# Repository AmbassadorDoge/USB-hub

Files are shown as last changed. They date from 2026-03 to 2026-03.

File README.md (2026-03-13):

# USB HUB

- 2 USB-C 2.0 ports
- 2 USB-A 3.1 gen 1 ports
- Using TUSB8042, USB-A upstream
- ~80x54mm, all recepticles

- Need USB-A to ~ to connect with computer
- Only for data, please do not try to use for charging!

Made this because I needed a cheap and small USB hub I could carry so that my main hub could be kept at home. 

## Assembly
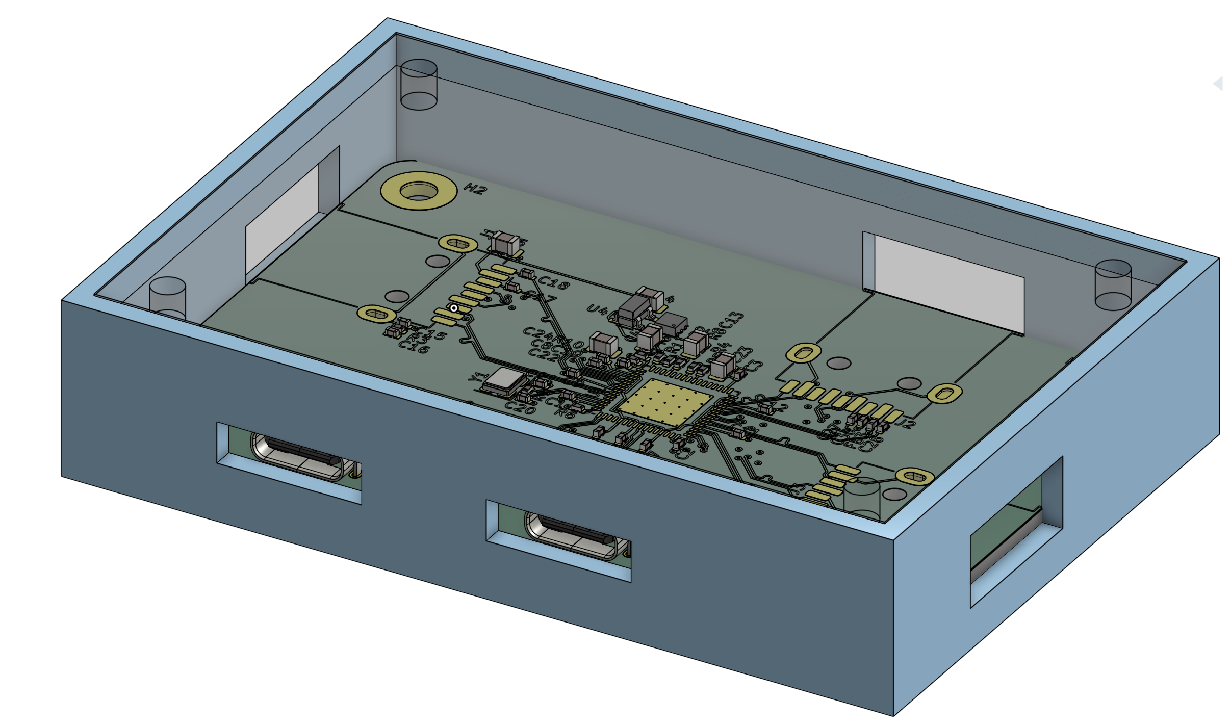
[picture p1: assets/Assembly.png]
asm


## PCB
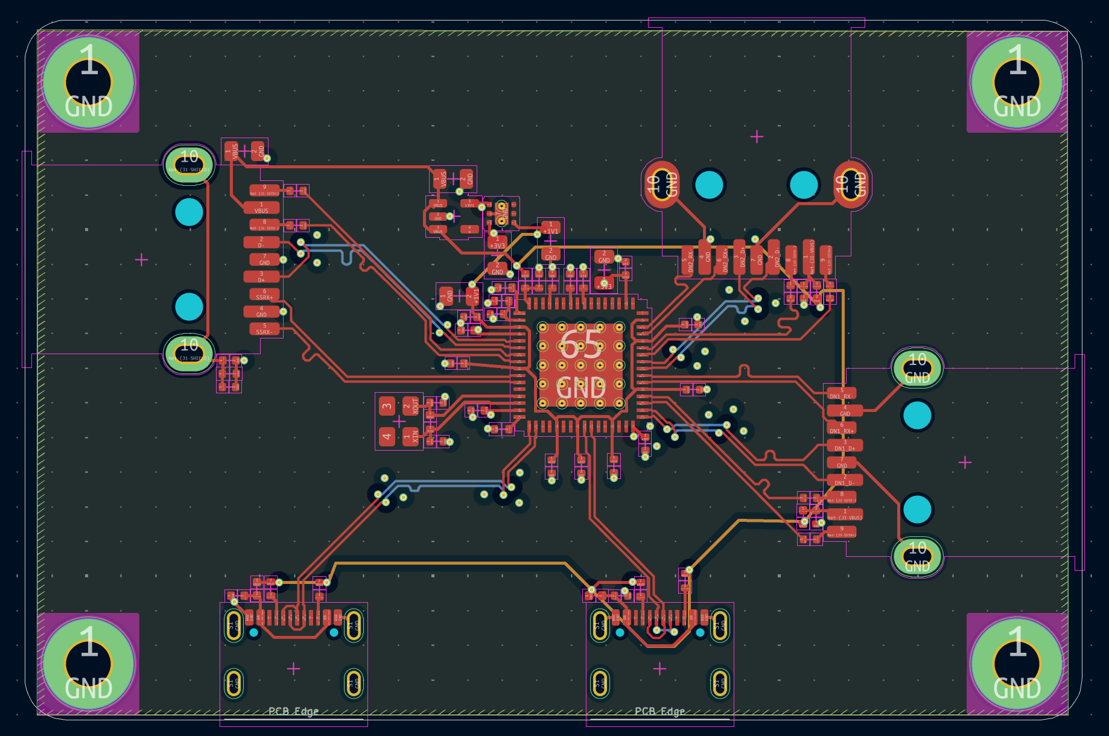
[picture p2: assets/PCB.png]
pcb


|item |price|link |
|---|-----|---|
|PCB | $7  | jlcpcb.com |
|PCBA | $45 | jlcpcb.com |
|acrylic| $5  | https://www.amazon.com/FixtureDisplays%C2%AE-Nominal-Plexiglass-Tabletop-15643-6X6-NF/dp/B099Z3Y54B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|
|total  | $52 | - |

Made using KiCad & Onshape
[Onshape link](https://cad.onshape.com/documents/166e42de1b24c1a1952d9a0a/w/ee2553dc721c4a7be2e464a8/e/28846ffd7bfde794f9e65d97)

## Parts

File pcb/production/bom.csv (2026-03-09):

Designator | Footprint | Quantity | Value | LCSC Part #
C1, C10, C11, C12, C15, C17, C18, C2, C22, C25, C26, C27, C28, C29, C3, C30, C31, C32, C6, C7, C8, C9 | 0402 | 22 | 0.1uF
C13, C14, C23, C24, C4, C5 | 0805 | 6 | 10uF
C16 | 0402 | 1 | 0.001uF
C19 | 0402 | 1 | 1uF
C20, C21 | 0402 | 2 | 18pF
FB1, FB2, FB3, FB4 | 0402 | 4 | 220@100MHz
J1, J2, J3 | USB3_A_Receptacle_Wuerth_692122030100 | 3 | USB3_A
J4, J5 | USB_C_Receptacle_GCT_USB4105-xx-A_16P_TopMnt_Horizontal | 2 | USB_C_Receptacle_USB2.0_16P
R1 | 0402 | 1 | 90.9k
R10, R2 | 0402 | 2 | 10k
R11, R12, R13, R14 | 0402 | 4 | 56k
R3, R9 | 0402 | 2 | 1M
R4, R5, R7, R8 | 0402 | 4 | 4.7k
R6 | 0402 | 1 | 9.53k
U1 | QFN-64-1EP_9x9mm_P0.5mm_EP6x6mm_ThermalVias | 1 | TUSB8041
U2 | WSON-6-1EP_2x2mm_P0.65mm_EP1x1.6mm_ThermalVias | 1 | LP5912-1.1DRV
U4 | SOT-23-5 | 1 | TLV75533PDBV
Y1 | Crystal_SMD_3225-4Pin_3.2x2.5mm | 1 | 24MHz

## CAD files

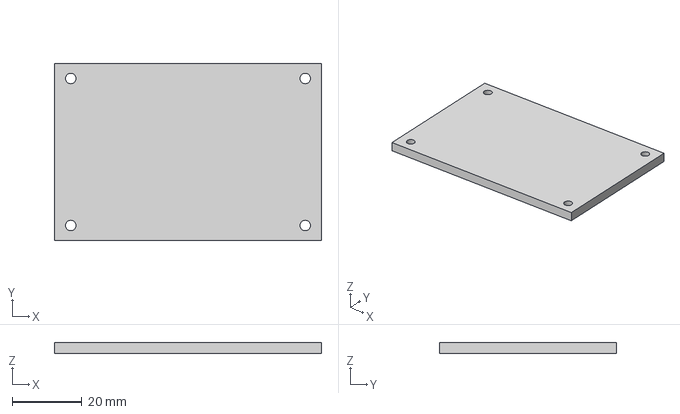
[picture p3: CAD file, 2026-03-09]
CAD/Acrylic Top.step
76.3 x 50.5 x 3.17 mm

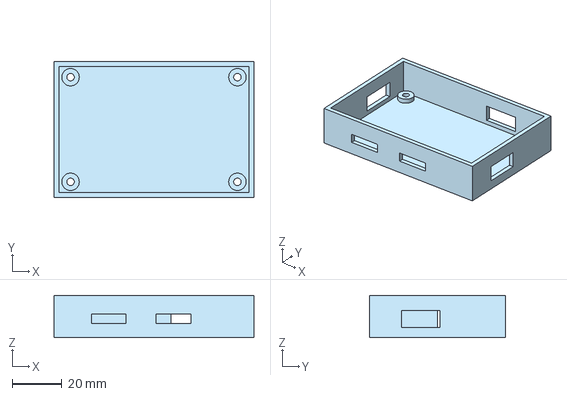
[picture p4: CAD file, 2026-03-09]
CAD/Holder.step
80.3 x 54.5 x 17.0 mm

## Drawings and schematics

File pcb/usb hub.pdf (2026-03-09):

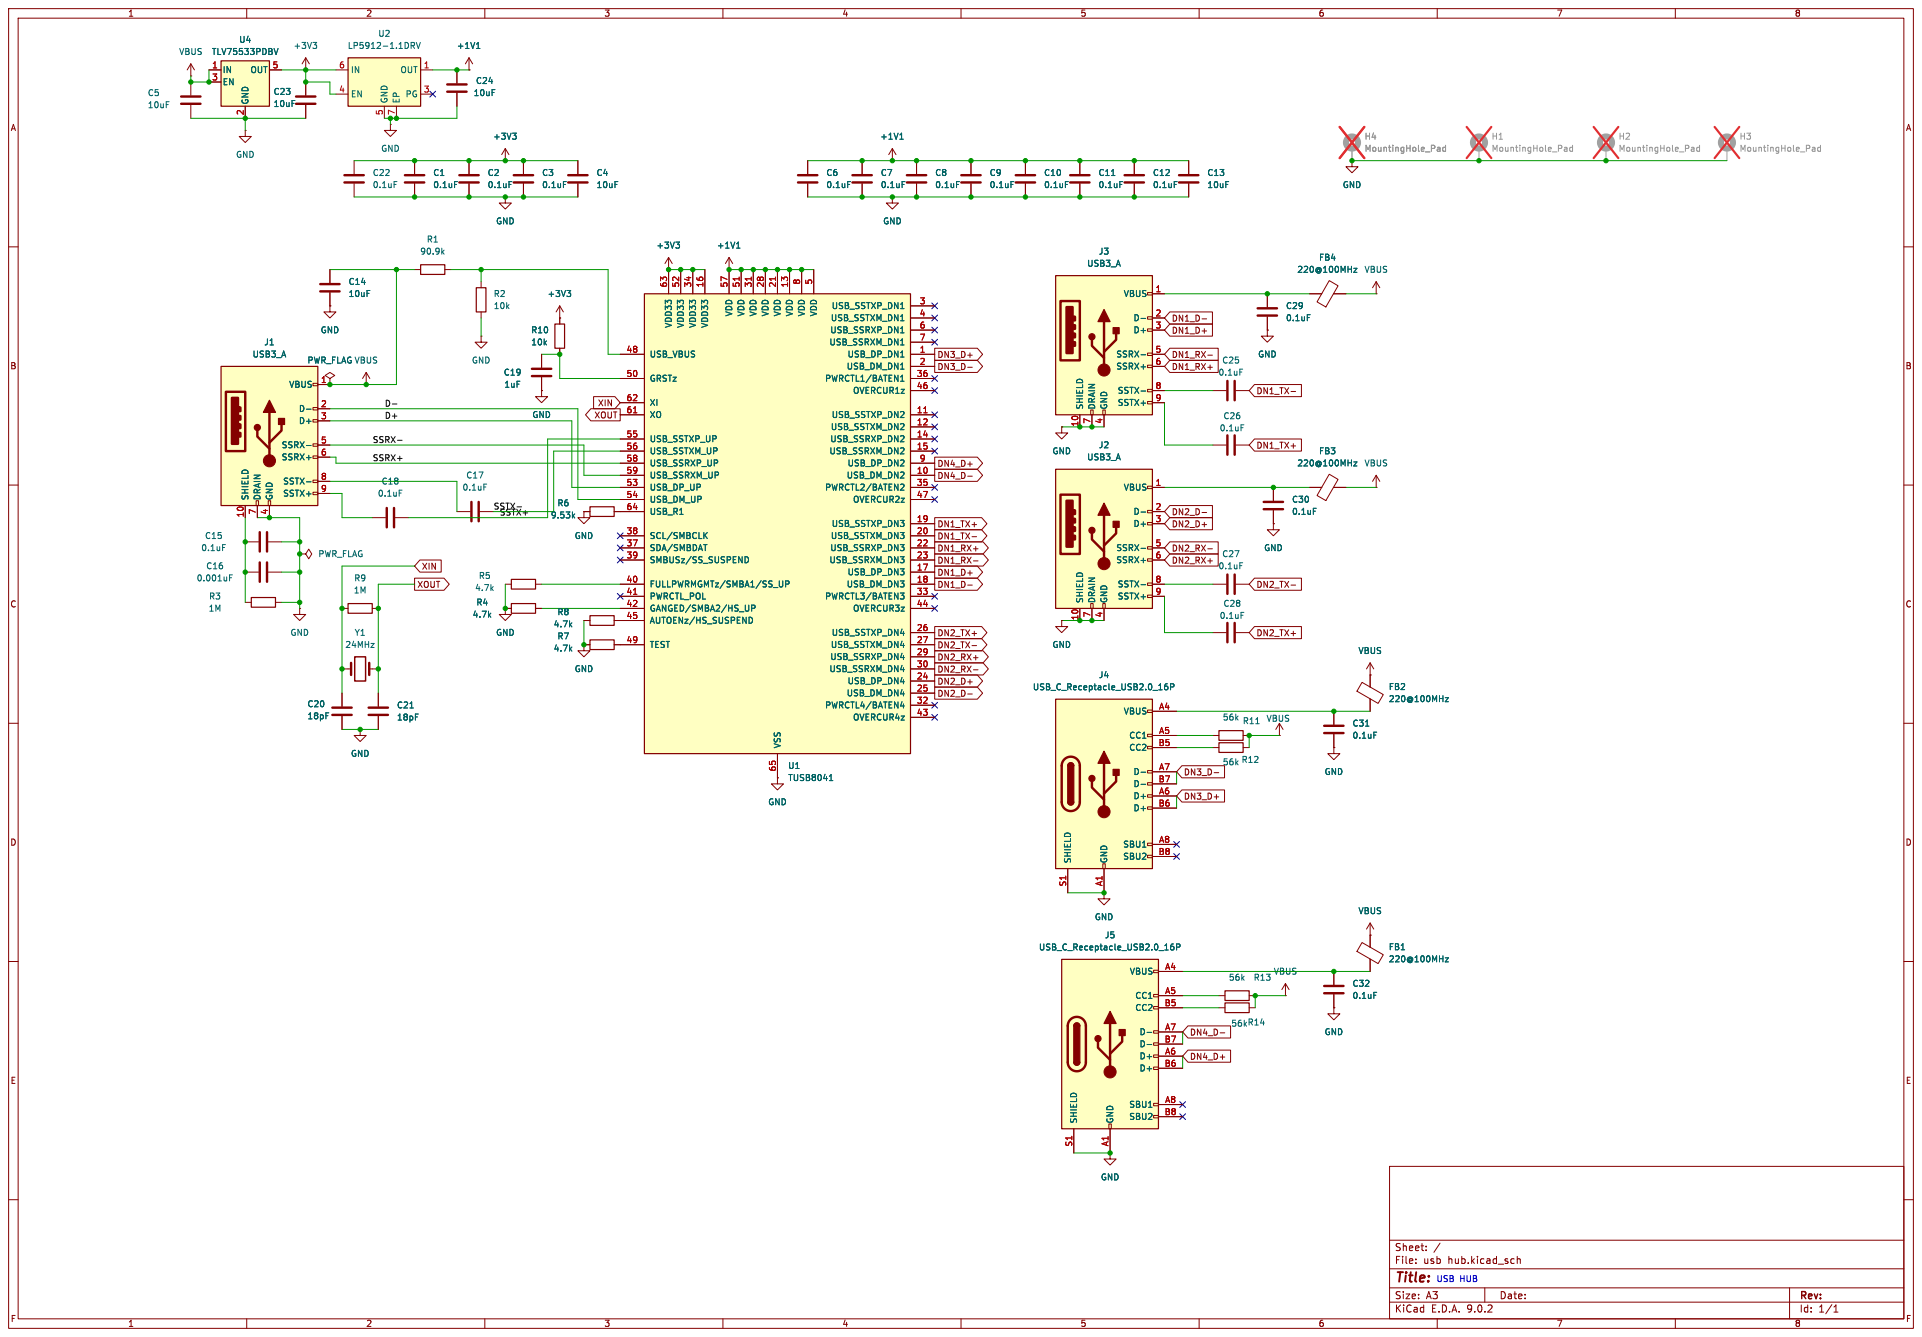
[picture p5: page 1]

2 OUT 5 U4 VBUS TLV75533PDBV USB_VBUS 48 GRSTz 50 XI 62 XO 61 USB_SSTXP_UP 55 USB_SSTXM_UP 56 USB_SSRXP_UP 58 USB_SSRXM_UP 59 USB_DP_UP 53 USB_DM_UP 54 USB_R1 64 SCL/SMBCLK 38 SDA/SMBDAT 37 SMBUSz/SS_SUSPEND 39 FULLPWRMGMTz/SMBA1/SS_UP 40 PWRCTL_POL 41 GANGED/SMBA2/HS_UP 42 AUTOENz/HS_SUSPEND 45 TEST 49 VDD33 63 VDD33 52 VDD33 34 VDD33 16 VDD 57 VDD 51 VDD 31 VDD 28 VDD 21 VSS 65 VDD 13 VDD

4 VBUS 1 D- 2 D+ 3 SSRX- 5 SSRX+ 6 SSTX- 8 SSTX+ 9 +3V3 +1V1 C6

4 VBUS 1 D- 2 D+ 3 SSRX- 5 SSRX+ 6 SSTX- 8 SSTX+ 9 C10

4 VBUS 1 D- 2 D+ 3 SSRX- 5 SSRX+ 6 SSTX- 8 SSTX+ 9

4 VBUS 1 D- 2 D+ 3 SSRX- 5 SSRX+ 6 SSTX- 8 SSTX+ 9 VBUS

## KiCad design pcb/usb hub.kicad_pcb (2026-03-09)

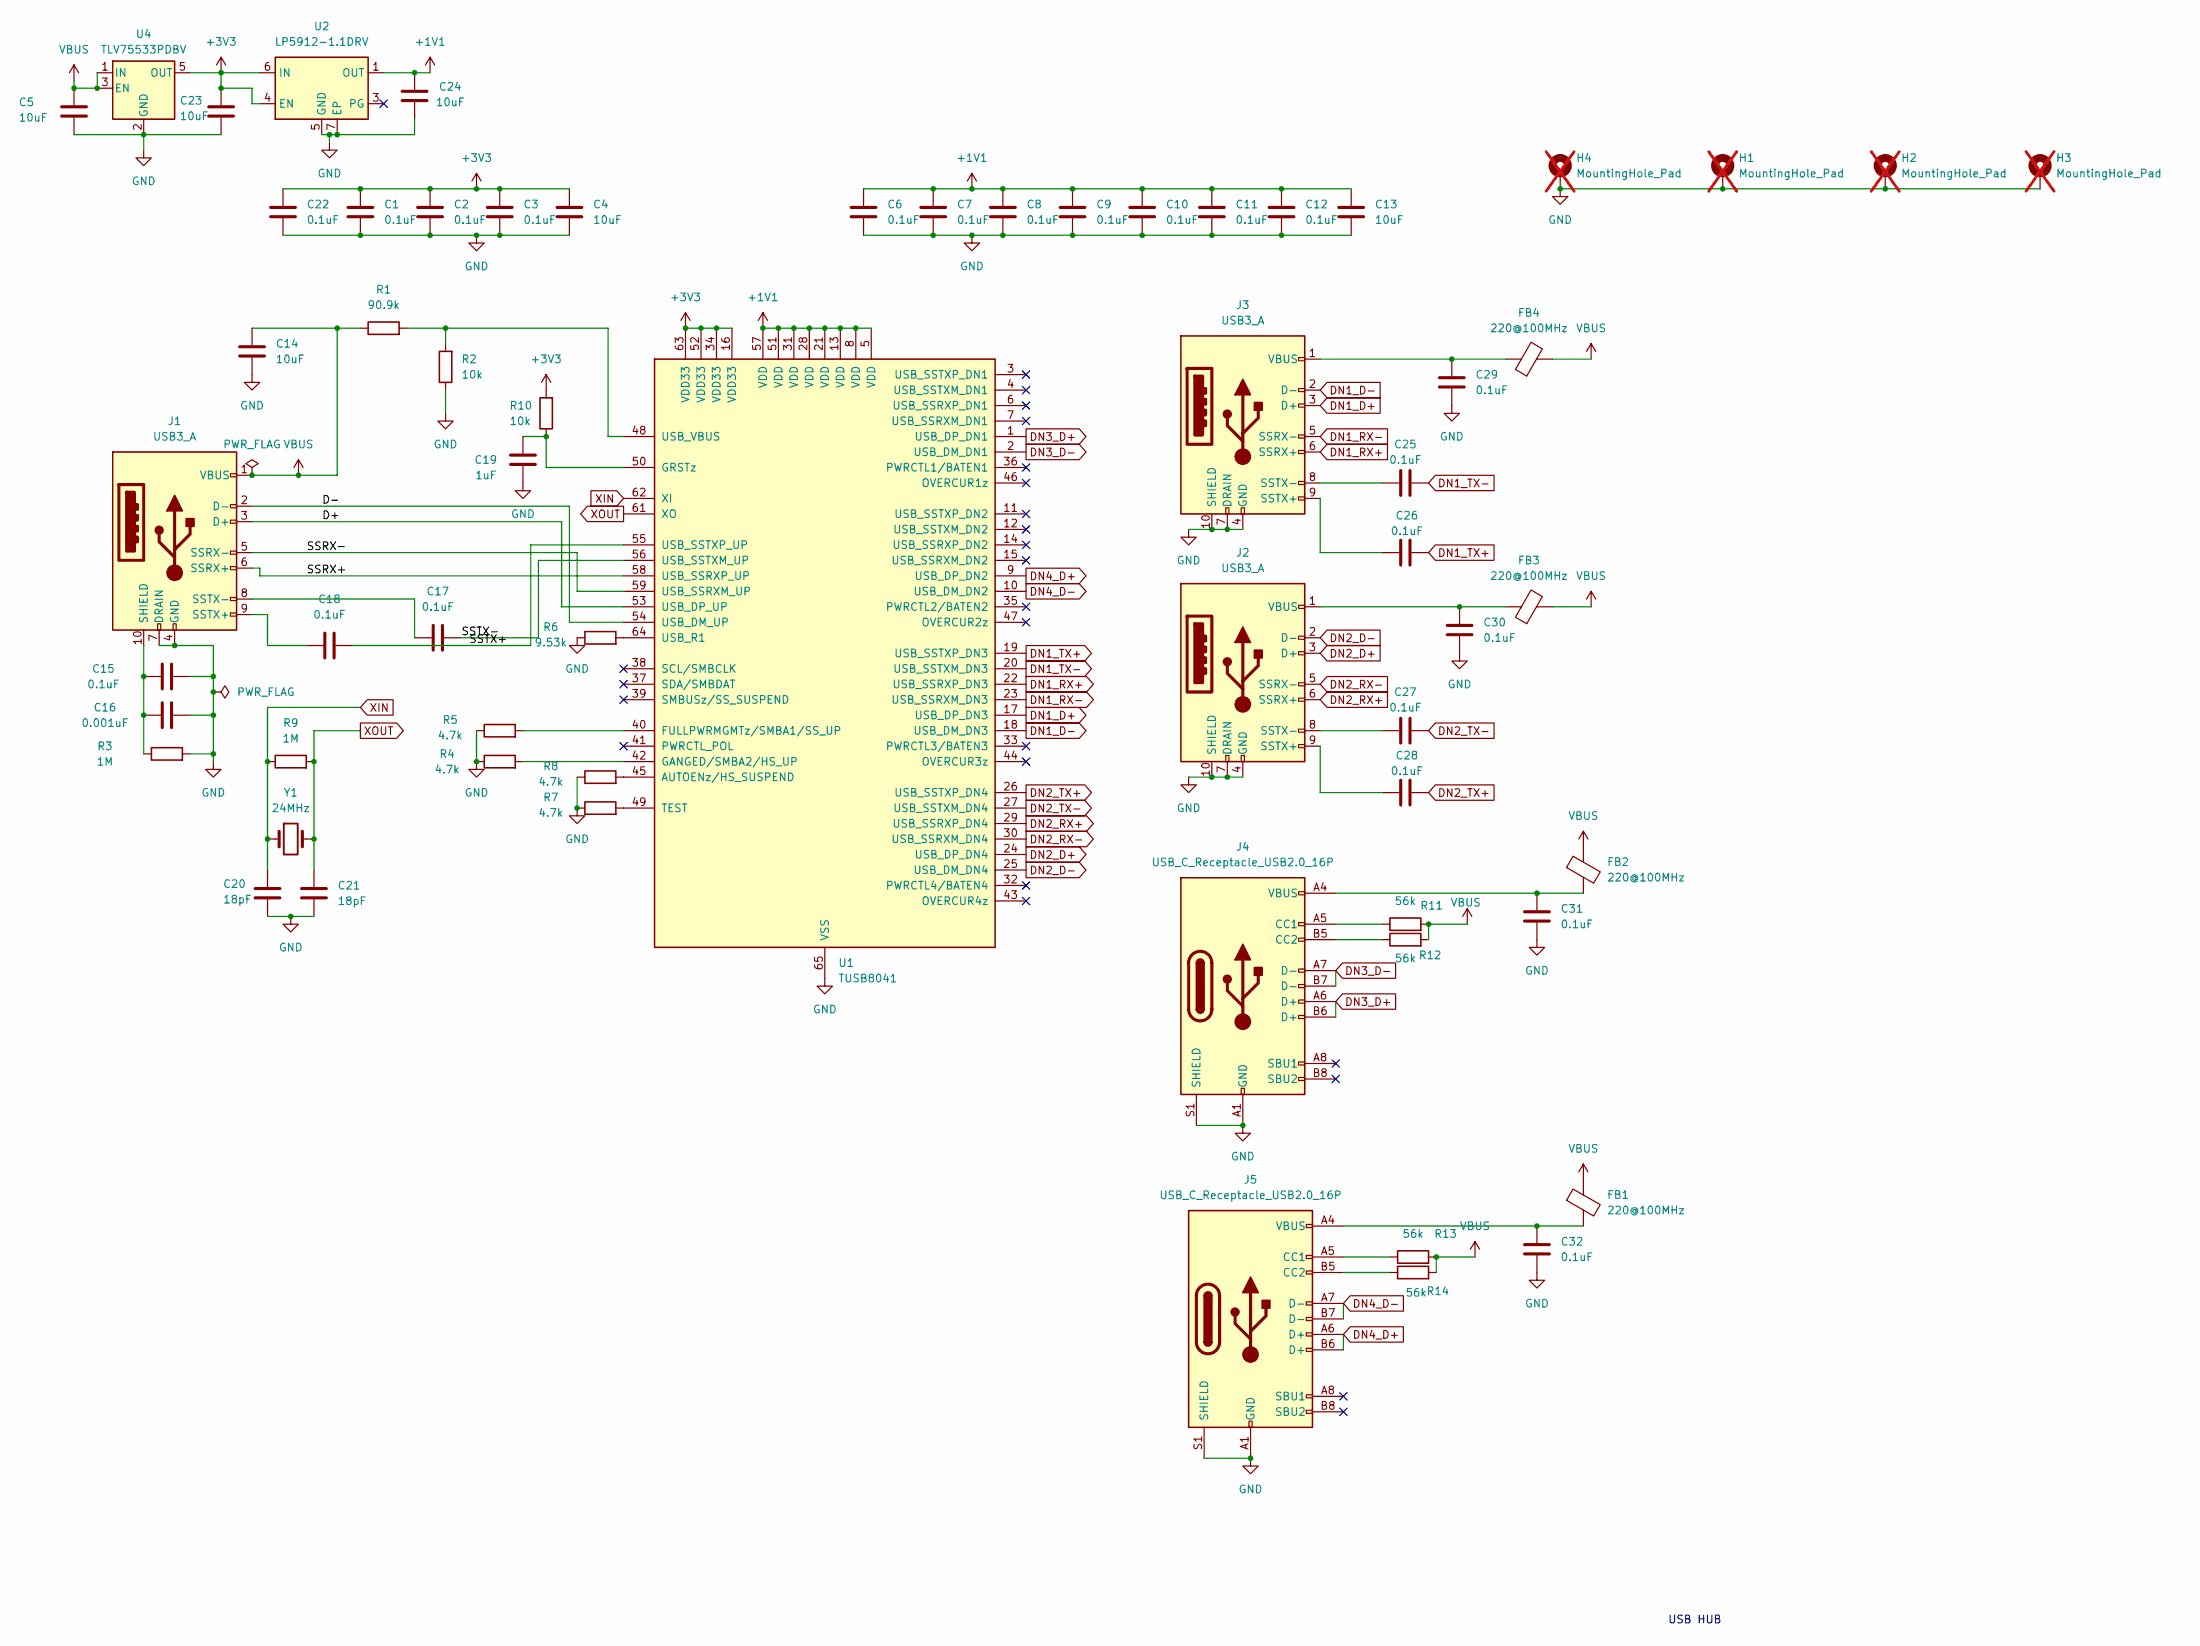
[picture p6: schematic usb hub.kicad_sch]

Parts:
C1, C2, C3, C6, C7, C8, C9, C10, C11, C12, C15, C17, C18, C22, C25, C26, C27, C28, C29, C30, C31, C32: 0.1uF; C_0402_1005Metric
C4, C5, C13, C14, C23, C24: 10uF; C_0805_2012Metric
C16: 0.001uF; C_0402_1005Metric
C19: 1uF; C_0402_1005Metric
C20, C21: 18pF; C_0402_1005Metric
FB1, FB2, FB3, FB4: 220@100MHz; L_0402_1005Metric
H1, H2, H3, H4: MountingHole_Pad; MountingHole_3.2mm_M3_Pad; not fitted
J1, J2, J3: USB3_A; USB3_A_Receptacle_Wuerth_692122030100
J4, J5: USB_C_Receptacle_USB2.0_16P; USB_C_Receptacle_GCT_USB4105-xx-A_16P_TopMnt_Horizontal
R1: 90.9k; R_0402_1005Metric
R2, R10: 10k; R_0402_1005Metric
R3, R9: 1M; R_0402_1005Metric
R4, R5, R7, R8: 4.7k; R_0402_1005Metric
R6: 9.53k; R_0402_1005Metric
R11, R12, R13, R14: 56k; R_0402_1005Metric
U1: TUSB8041; QFN-64-1EP_9x9mm_P0.5mm_EP6x6mm_ThermalVias
U2: LP5912-1.1DRV; WSON-6-1EP_2x2mm_P0.65mm_EP1x1.6mm_ThermalVias
U4: TLV75533PDBV; SOT-23-5
Y1: 24MHz; Crystal_SMD_3225-4Pin_3.2x2.5mm

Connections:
+1V1: C6.1, C7.1, C8.1, C9.1, C10.1, C11.1, C12.1, C13.1, C24.2, U1.5 (VDD), U1.8 (VDD), U1.13 (VDD), U1.21 (VDD), U1.28 (VDD), U1.31 (VDD), U1.51 (VDD), U1.57 (VDD), U2.1 (OUT)
+3V3: C1.1, C2.1, C3.1, C4.1, C22.1, C23.1, R10.2, U1.16 (VDD33), U1.34 (VDD33), U1.52 (VDD33), U1.63 (VDD33), U2.4 (EN), U2.6 (IN), U4.5 (OUT)
/D+: J1.3 (D+), U1.53 (USB_DP_UP)
/D-: J1.2 (D-), U1.54 (USB_DM_UP)
/SSRX+: J1.6 (SSRX+), U1.58 (USB_SSRXP_UP)
/SSRX-: J1.5 (SSRX-), U1.59 (USB_SSRXM_UP)
/SSTX+: C18.2, U1.55 (USB_SSTXP_UP)
/SSTX-: C17.2, U1.56 (USB_SSTXM_UP)
DN1_D+: J3.3 (D+), U1.17 (USB_DP_DN3)
DN1_D-: J3.2 (D-), U1.18 (USB_DM_DN3)
DN1_RX+: J3.6 (SSRX+), U1.22 (USB_SSRXP_DN3)
DN1_RX-: J3.5 (SSRX-), U1.23 (USB_SSRXM_DN3)
DN1_TX+: C26.2, U1.19 (USB_SSTXP_DN3)
DN1_TX-: C25.2, U1.20 (USB_SSTXM_DN3)
DN2_D+: J2.3 (D+), U1.24 (USB_DP_DN4)
DN2_D-: J2.2 (D-), U1.25 (USB_DM_DN4)
DN2_RX+: J2.6 (SSRX+), U1.29 (USB_SSRXP_DN4)
DN2_RX-: J2.5 (SSRX-), U1.30 (USB_SSRXM_DN4)
DN2_TX+: C28.2, U1.26 (USB_SSTXP_DN4)
DN2_TX-: C27.2, U1.27 (USB_SSTXM_DN4)
DN3_D+: J4.A6 (D+), J4.B6 (D+), U1.1 (USB_DP_DN1)
DN3_D-: J4.A7 (D-), J4.B7 (D-), U1.2 (USB_DM_DN1)
DN4_D+: J5.A6 (D+), J5.B6 (D+), U1.9 (USB_DP_DN2)
DN4_D-: J5.A7 (D-), J5.B7 (D-), U1.10 (USB_DM_DN2)
GND: C1.2, C2.2, C3.2, C4.2, C5.2, C6.2, C7.2, C8.2, C9.2, C10.2, C11.2, C12.2, C13.2, C14.2, C15.2, C16.2, C19.1, C20.2, C21.2, C22.2, C23.2, C24.1, C29.1, C30.1, C31.1, C32.1, H1.1, H2.1, H3.1, H4.1, J1.4 (GND), J1.7 (DRAIN), J2.4 (GND), J2.7 (DRAIN), J2.10 (SHIELD), J3.4 (GND), J3.7 (DRAIN), J3.10 (SHIELD), J4.A1 (GND), J4.A12 (GND), J4.B1 (GND), J4.B12 (GND), J4.S1 (SHIELD), J5.A1 (GND), J5.A12 (GND), J5.B1 (GND), J5.B12 (GND), J5.S1 (SHIELD), R2.1, R3.2, R4.1, R5.1, R6.1, R7.1, R8.1, U1.65 (VSS), U2.5 (GND), U2.7 (EP), U4.2 (GND)
unnamed: C31.2, FB2.2, J4.A4 (VBUS), J4.A9 (VBUS), J4.B4 (VBUS), J4.B9 (VBUS)
unnamed: C32.2, FB1.2, J5.A4 (VBUS), J5.A9 (VBUS), J5.B4 (VBUS), J5.B9 (VBUS)
unnamed: C15.1, C16.1, J1.10 (SHIELD), R3.1
unnamed: C18.1, J1.9 (SSTX+)
unnamed: C17.1, J1.8 (SSTX-)
unnamed: C28.1, J2.9 (SSTX+)
unnamed: C27.1, J2.8 (SSTX-)
unnamed: C30.2, FB3.1, J2.1 (VBUS)
unnamed: C26.1, J3.9 (SSTX+)
unnamed: C25.1, J3.8 (SSTX-)
unnamed: C29.2, FB4.1, J3.1 (VBUS)
unnamed: J4.A5 (CC1), R11.1
unnamed: J4.B5 (CC2), R12.1
unnamed: J5.A5 (CC1), R13.1
unnamed: J5.B5 (CC2), R14.1
unnamed: R8.2, U1.45 (AUTOENz/HS_SUSPEND)
unnamed: R5.2, U1.40 (FULLPWRMGMTz/SMBA1/SS_UP)
unnamed: R4.2, U1.42 (GANGED/SMBA2/HS_UP)
unnamed: C19.2, R10.1, U1.50 (GRSTz)
unnamed: R7.2, U1.49 (TEST)
unnamed: R6.2, U1.64 (USB_R1)
unnamed: R1.2, R2.2, U1.48 (USB_VBUS)
VBUS: C5.1, C14.1, FB1.1, FB2.1, FB3.2, FB4.2, J1.1 (VBUS), R1.1, R11.2, R12.2, R13.2, R14.2, U4.1 (IN), U4.3 (EN)
XIN: C20.1, R9.1, U1.62 (XI), Y1.1
XOUT: C21.1, R9.2, U1.61 (XO), Y1.2

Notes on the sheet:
USB HUB

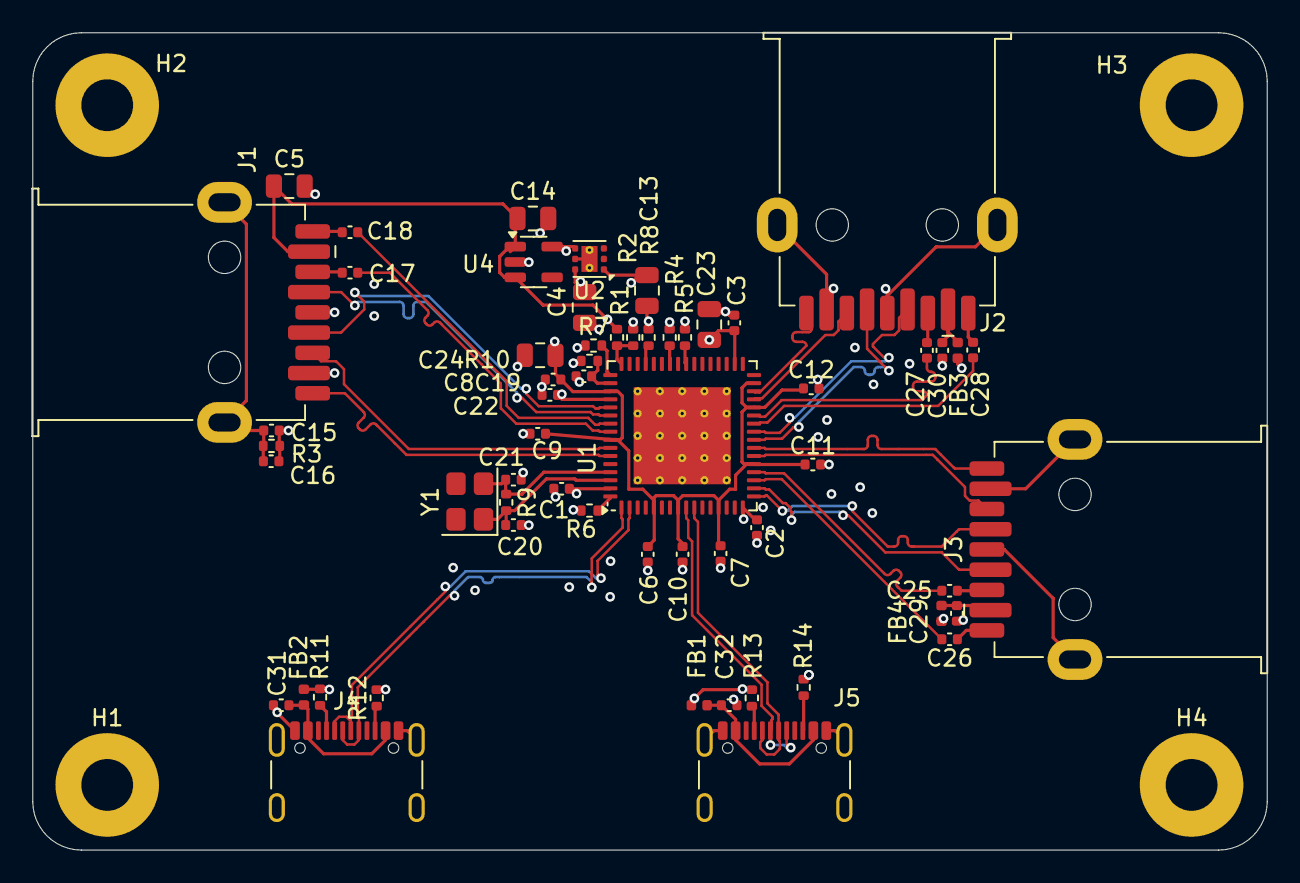
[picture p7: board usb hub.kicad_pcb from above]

Board: 4 copper layers, 76.3 x 50.5 mm, 63 parts (0 on the bottom side), 50 nets.
